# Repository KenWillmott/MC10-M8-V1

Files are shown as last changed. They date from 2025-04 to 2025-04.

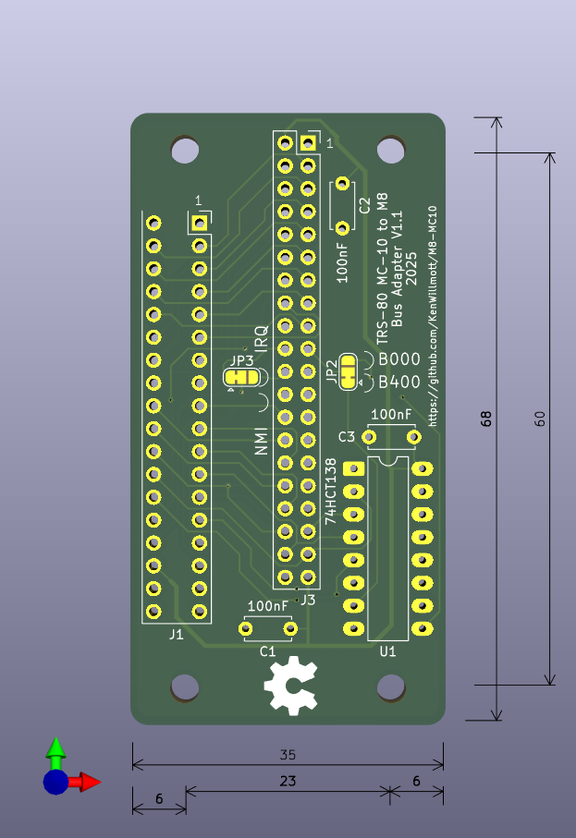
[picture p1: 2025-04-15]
board3d.png

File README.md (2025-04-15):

# MC10-M8-V1
Basic TRS-80 MC-10 to M8 expansion interface

board3d

## Description
Allows one M8 peripheral expansion card to operate from the expansion port on the rear of the TRS-80 MC-10 microcomputer. The circuit decodes an I/O slot at 0xB400-0xB7FF, so any M8 peripheral card will be addressed by the MC-10 at that location, plus any internal offset that the card uses. In order to prevent a hardware bus conflict when accessing those location, the SEL line on the MC-10 interface is activated to disable its internal devices mapped to the same locations.

Note: Gating with the CPU E signal is not performed by the interface card, it is always done on the M8 card. But, this is quite easy to do on the M8 card and some cards can do it without additional logic, since some I/O IC's perform E gating internally (such as 6522 VIA, Motorola MC6850, MC6821 etc.).

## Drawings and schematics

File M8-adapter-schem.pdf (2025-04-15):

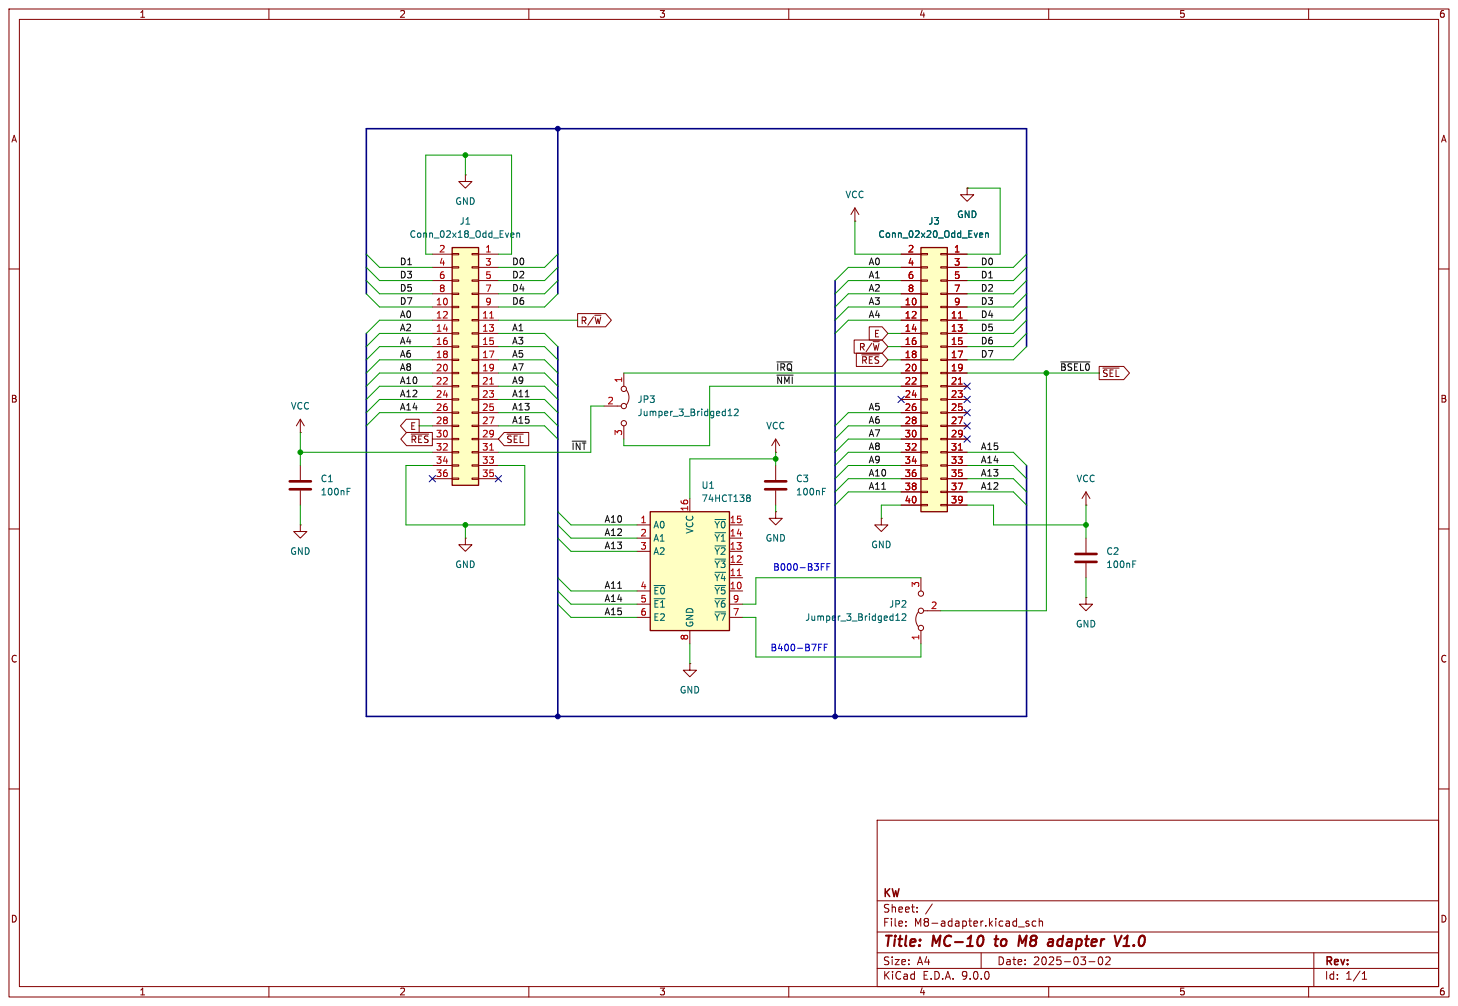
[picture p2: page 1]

File: M8-adapter.kicad_sch Sheet: / KW

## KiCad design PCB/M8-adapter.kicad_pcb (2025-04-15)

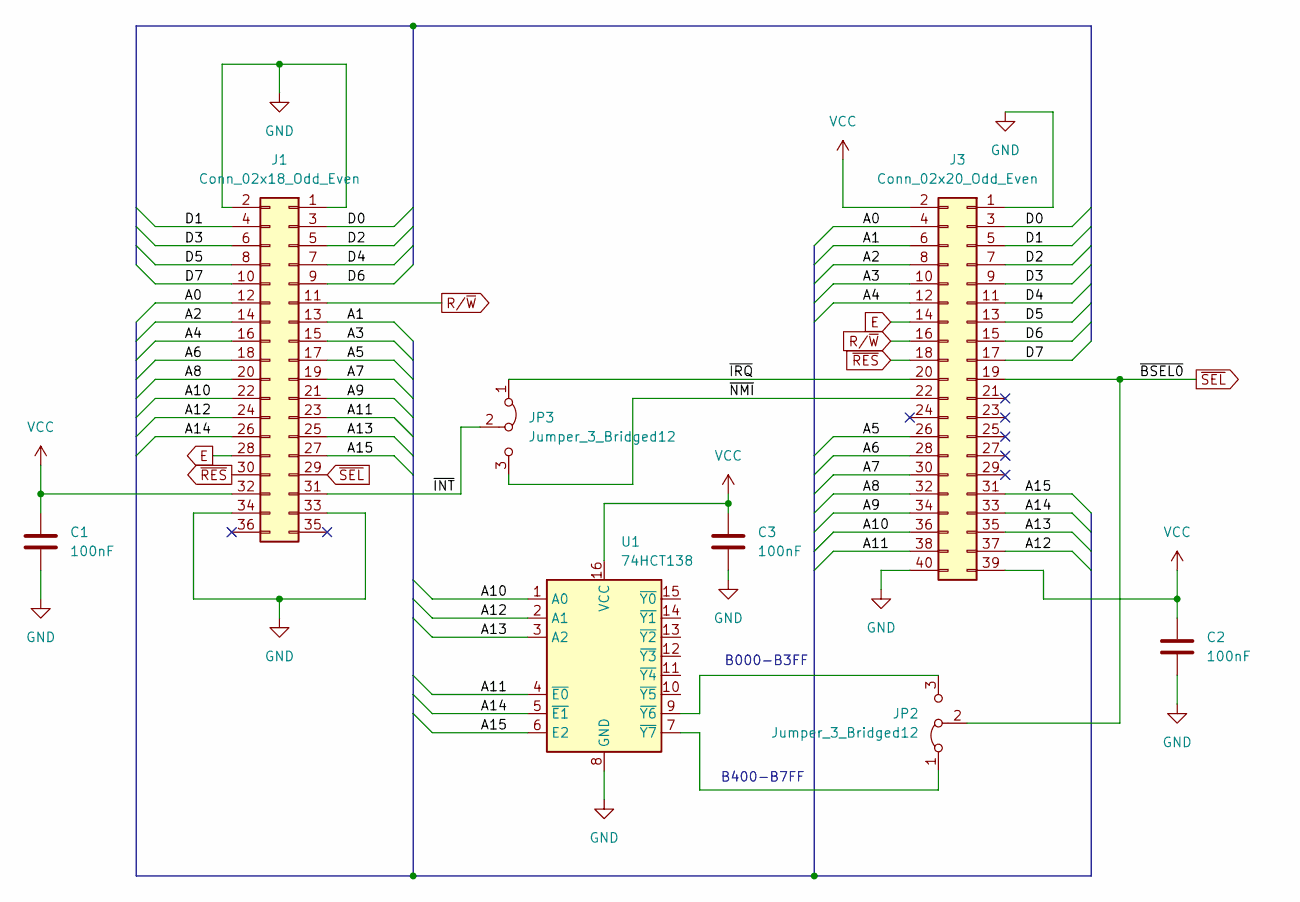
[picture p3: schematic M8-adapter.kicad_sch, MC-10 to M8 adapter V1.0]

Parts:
C1, C2, C3: 100nF; C_Disc_D5.0mm_W2.5mm_P5.00mm
J1: Conn_02x18_Odd_Even; Edge_Conn_2x18_P2.54mm_RA
J3: Conn_02x20_Odd_Even; PinSocket_2x20_P2.54mm_Vertical
JP2, JP3: Jumper_3_Bridged12; SolderJumper-3_P1.3mm_Bridged12_RoundedPad1.0x1.5mm
U1: 74HCT138; DIP-16_W7.62mm_LongPads

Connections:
/A0: J1.12, J3.4
/A1: J1.13, J3.6
/A2: J1.14, J3.8
/A3: J1.15, J3.10
/A4: J1.16, J3.12
/A5: J1.17, J3.26
/A6: J1.18, J3.28
/A7: J1.19, J3.30
/A8: J1.20, J3.32
/A9: J1.21, J3.34
/A10: J1.22, J3.36, U1.1 (A0)
/A11: J1.23, J3.38, U1.4 (~E0)
/A12: J1.24, J3.37, U1.2 (A1)
/A13: J1.25, J3.35, U1.3 (A2)
/A14: J1.26, J3.33, U1.5 (~E1)
/A15: J1.27, J3.31, U1.6 (E2)
/D0: J1.3, J3.3
/D1: J1.4, J3.5
/D2: J1.5, J3.7
/D3: J1.6, J3.9
/D4: J1.7, J3.11
/D5: J1.8, J3.13
/D6: J1.9, J3.15
/D7: J1.10, J3.17
/~INT: J1.31, JP3.2 (C)
/~IRQ: J3.20, JP3.1 (A)
/~NMI: J3.22, JP3.3 (B)
E: J1.28, J3.14
GND: C1.2, C2.2, C3.2, J1.1, J1.2, J1.33, J1.34, J3.1, J3.40, U1.8 (GND)
unnamed: JP2.1 (A), U1.7 (~Y7)
unnamed: JP2.3 (B), U1.9 (~Y6)
R/~W: J1.11, J3.16
VCC: C1.1, C2.1, C3.1, J1.32, J3.2, J3.39, U1.16 (VCC)
~RES: J1.30, J3.18
~SEL: J1.29, J3.19, JP2.2 (C)

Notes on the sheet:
B400-B7FF
B000-B3FF

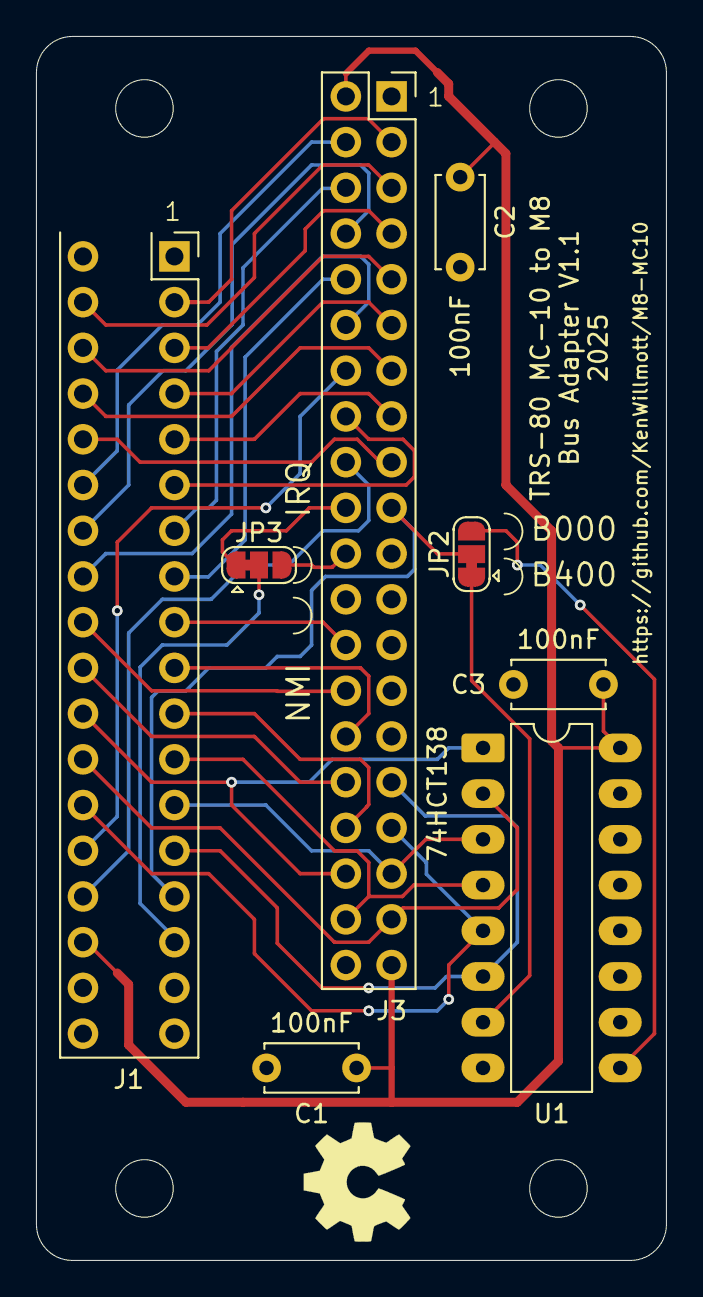
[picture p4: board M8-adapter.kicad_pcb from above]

Board: 2 copper layers, 35.0 x 68.0 mm, 8 parts (0 on the bottom side), 35 nets.
